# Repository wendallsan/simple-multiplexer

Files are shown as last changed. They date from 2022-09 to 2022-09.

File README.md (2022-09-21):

# SynthUx Academy Simple Board Multiplexer Daughterboard

This is a small PCB that is designed to fit on the perfboard section at the bottom right of the Simple Board from [SynthUX Academy](https://synthux.academy/simple). 

## Headers Explained

There are two headers on the board, one 2x8 header accepts all the analog inputs, while the 1x8 header provides connectivity to the Daisy Seed.  

### Analog Inputs Header
```
Pin   Mux IC  Channel
1	1   X0
2	1     X1
3	1     X2
4	1     X3
5	1     X4
6       1     X5
7	1     X6
8	1     X7
9	2     X0
10	2     X1
11	2     X2
12	2     X3
13	2     X4
14	2     X5
15	2     X6
16	2     X7
```

### Daisy Seed I/O Header
```
+ - positive voltage input-- connects  Pin 21 (AGND) of the Daisy Seed
A - Channel Select A
B - Channel Select B
C - Channel Select C
M1 - Mux 1 Out
M2 - Mux 2 Out
GND - ground -- connect to your Ground network (and Pins 20 and 40 on the Daisy Seed)
```  
Pin 7 on the I/O header is not used.  

## Bill of Materials  

```
2x CD4051 IC's in SOIC-16 format
2x 10nF capacitors in 0805 format
1x 2x8 female header with 2.54mm spacing
1x 1x8 female header with 2.54mm spacing  
4x single male pins for mounting the board
```

## Images  




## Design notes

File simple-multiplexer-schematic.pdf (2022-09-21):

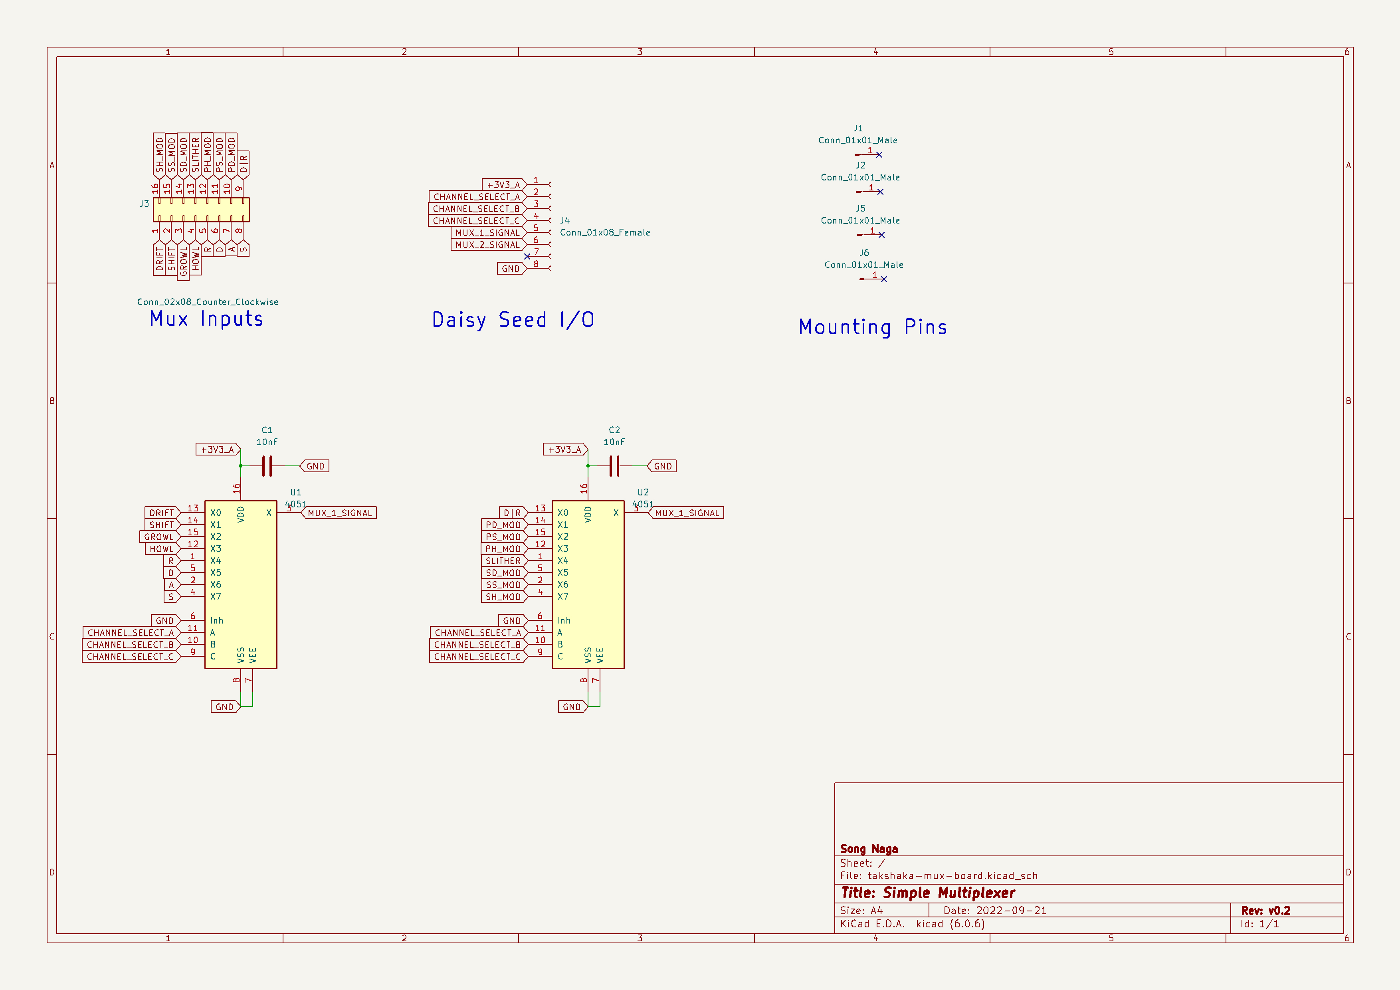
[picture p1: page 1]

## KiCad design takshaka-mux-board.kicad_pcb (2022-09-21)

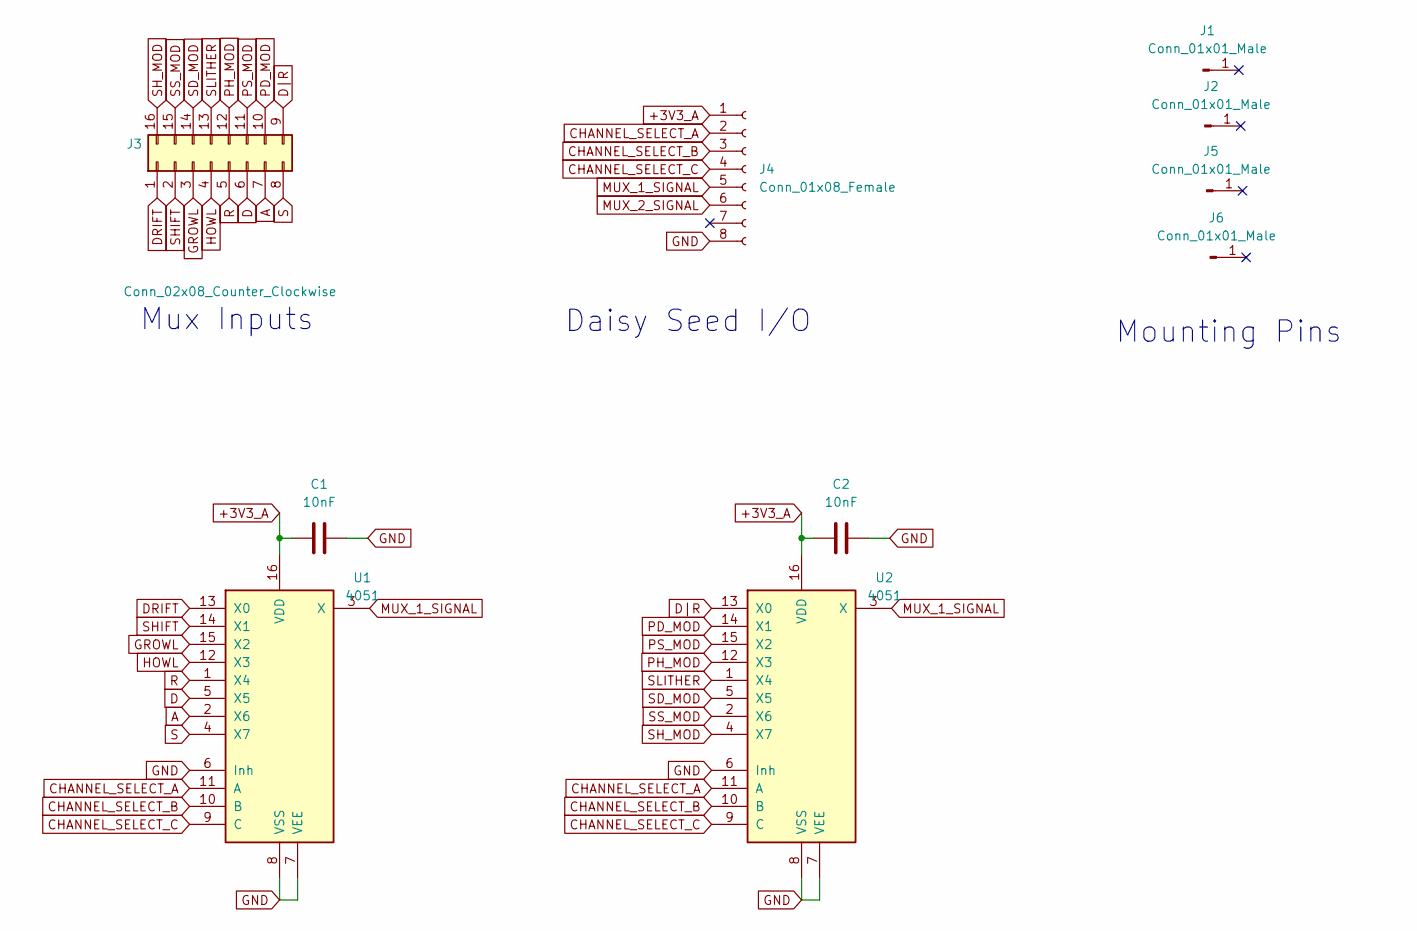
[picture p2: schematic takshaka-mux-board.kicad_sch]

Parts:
C1, C2: 10nF; C_0805_2012Metric
J1, J2, J5, J6: Conn_01x01_Male; PinHeader_1x01_P2.54mm_Vertical
J3: Conn_02x08_Counter_Clockwise; PinSocket_2x08_P2.54mm_Vertical
J4: Conn_01x08_Female; PinSocket_1x08_P2.54mm_Vertical
U1, U2: 4051; SOIC-16_3.9x9.9mm_P1.27mm

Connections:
+3V3_A: C1.1, C2.1, J4.1, U1.16 (VDD), U2.16 (VDD)
A: J3.7, U1.2 (X6)
CHANNEL_SELECT_A: J4.2, U1.11 (A), U2.11 (A)
CHANNEL_SELECT_B: J4.3, U1.10 (B), U2.10 (B)
CHANNEL_SELECT_C: J4.4, U1.9 (C), U2.9 (C)
D: J3.6, U1.5 (X5)
DRIFT: J3.1, U1.13 (X0)
D|R: J3.9, U2.13 (X0)
GND: C1.2, C2.2, J4.8, U1.6 (Inh), U1.7 (VEE), U1.8 (VSS), U2.6 (Inh), U2.7 (VEE), U2.8 (VSS)
GROWL: J3.3, U1.15 (X2)
HOWL: J3.4, U1.12 (X3)
MUX_1_SIGNAL: J4.5, U1.3 (X), U2.3 (X)
MUX_2_SIGNAL: J4.6
PD_MOD: J3.10, U2.14 (X1)
PH_MOD: J3.12, U2.12 (X3)
PS_MOD: J3.11, U2.15 (X2)
R: J3.5, U1.1 (X4)
S: J3.8, U1.4 (X7)
SD_MOD: J3.14, U2.5 (X5)
SHIFT: J3.2, U1.14 (X1)
SH_MOD: J3.16, U2.4 (X7)
SLITHER: J3.13, U2.1 (X4)
SS_MOD: J3.15, U2.2 (X6)

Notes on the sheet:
Daisy Seed I/O
Mux Inputs
Mounting Pins

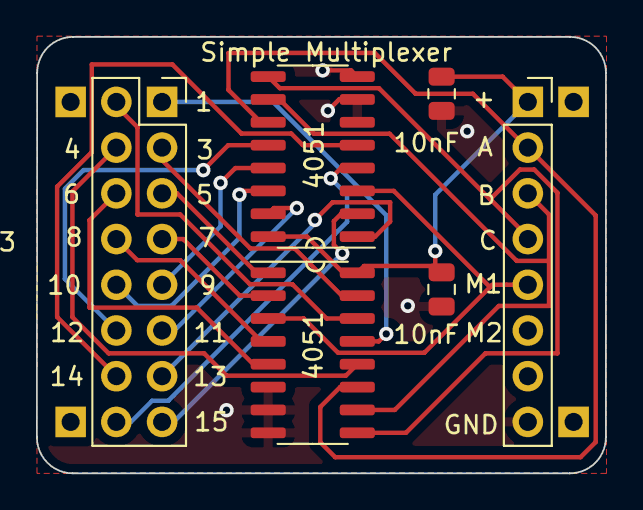
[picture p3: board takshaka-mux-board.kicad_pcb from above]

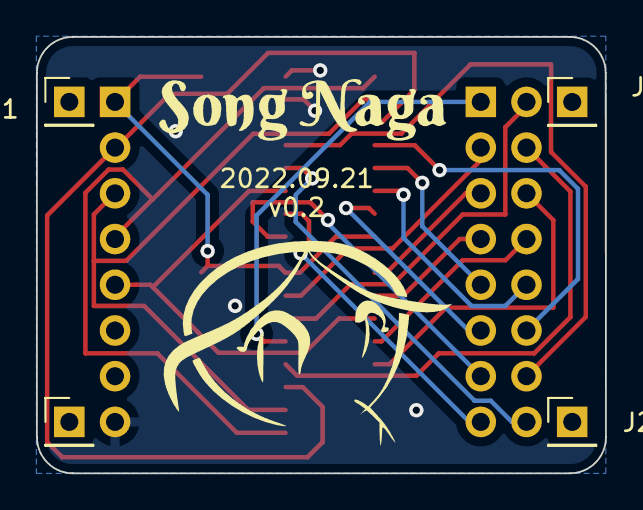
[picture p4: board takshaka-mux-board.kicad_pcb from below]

Board: 2 copper layers, 31.6 x 24.2 mm, 12 parts (6 on the bottom side), 22 nets.

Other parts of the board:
G1, G2: LOGO

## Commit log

2022-09-21 Initial commit.
    [takshaka-mux-board-rounded-B_Cu.gbr, takshaka-mux-board-rounded-B_Mask.gbr, takshaka-mux-board-rounded-B_Paste.gbr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]
2022-09-21 rebuilt gerbers files.
    [takshaka-mux-board-rounded-B_Cu.gbr, takshaka-mux-board-rounded-B_Mask.gbr, takshaka-mux-board-rounded-B_Paste.gbr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]
2022-09-21 added schematic PDF.
    [takshaka-mux-board.kicad_sch]
